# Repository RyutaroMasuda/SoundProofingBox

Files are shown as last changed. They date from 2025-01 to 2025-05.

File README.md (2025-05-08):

# SoundProofingBox_RZ420
RZ420用の防音箱。assy-SoundProofingBox_RZ420.SLDASMが最上位アセンブリです。部品リストもあります。わわわ
## License

MIT License

Copyright (c) 2025 隆太郎 益田

Permission is hereby granted, free of charge, to any person obtaining a copy...

## 設計外観

## 加工時の注意
- MDFとアルミフレームの接合分のねじ穴は、端から10mmでさえあれば、縦の位置はがばがばでもよい。専用の治具を別途プリント部品で製作するのが良い。
   
- 必要な加工はMDFに対するねじ穴開けと配線用の100mmの円形穴のみである。
  - 円形穴はサークルカッタを使用する。
- 鬼目ナットはM5のものはねじ込み型で、M3のものは打ち込み型である。これはM3に打ち込み型しかなかったからである。
  - 打ち込み型の方が取れやすいらしい。
  - 鬼目ナットは貫通穴ではないので注意すること。
## 組み立て時の注意
- 振動用にすべてのねじにロックタイト中強度を塗布する。
  - ねじを締める前にパーツクリーナで洗浄するのがbetter
- 面倒だったので防音マットをCAD上に反映させていない。
  - 防音マットは300-300-0.9で、カッターやハサミで切断可能なので、組み立て時に同時に加工する。
  - 専用の両面テープで接着する。

## 参考文献
https://www.neji-concier.com/column/what-kind-of-onime-nut.html
## 謝辞
RZ420本体の方のCADを作ったのは12期の木野本さんです。大変助かりました。ありがとう。

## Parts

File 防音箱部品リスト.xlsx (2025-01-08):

入力順 | 品名 | 型番 | 必要個数 | 予備 | 購入サイト | 合計金額（税込み） | 発注先 | 備考
1 | 防音箱用M3ねじ |  | 1 | 0 | https://amzn.asia/d/9brNjJE | 1399 | amazon
2 | サークルカッター |  | 1 | 0 | https://amzn.asia/d/35P8lY7 | 1730 | amazon | 100mmMDF穴あけ用
3 | ねじロック |  | 1 | 0 | https://www.amazon.co.jp/%E3%83%98%E3%83%B3%E3%82%B1%E3%83%AB%E3%82%B8%E3%83%A3%E3%83%91%E3%83%B3-Henkel-Japan-LOCTITE-%E9%87%91%E5%B1%9E%E8%A3%BD%E3%81%AD%E3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 | 881 | amazon
4 | 木工用ドリルビット |  | 1 | 0 | https://www.amazon.co.jp/YOKOCUT-%E3%83%89%E3%83%AA%E3%83%AB%E3%83%93%E3%83%83%E3%83%88%E3%82%BB%E3%83%83%E3%83%88-%E6%9C%A8%E5%B7%A5%E7%94%A8%E3%83%89%E3%83%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 | 900 | amazon
5 | MDF 595×640×15 |  | 1 | 0 | https://www.zaiichi.com/mdf/1500.html |  | 木工素材の材木屋ざいいち | カッティングサービスを利用。金額不明。見積もり申請をサイトから提出
6 | MDF 310×595×15 |  | 1 | 0 | https://www.zaiichi.com/mdf/1500.html |  | 木工素材の材木屋ざいいち | カッティングサービスを利用。金額不明。見積もり申請をサイトから提出
7 | MDF 595×615×15 |  | 1 | 0 | https://www.zaiichi.com/mdf/1500.html |  | 木工素材の材木屋ざいいち | カッティングサービスを利用。金額不明。見積もり申請をサイトから提出
8 | MDF 535×595×15 |  | 1 | 0 | https://www.zaiichi.com/mdf/1500.html |  | 木工素材の材木屋ざいいち | カッティングサービスを利用。金額不明。見積もり申請をサイトから提出
9 | MDF 105×595×15 |  | 1 | 0 | https://www.zaiichi.com/mdf/1500.html |  | 木工素材の材木屋ざいいち | カッティングサービスを利用。金額不明。見積もり申請をサイトから提出
10 | MDF 595×925×15 |  | 1 | 0 | https://www.zaiichi.com/mdf/1500.html |  | 木工素材の材木屋ざいいち | カッティングサービスを利用。金額不明。見積もり申請をサイトから提出
11 | MDF 640×955×15 |  | 2 | 0 | https://www.zaiichi.com/mdf/1500.html |  | 木工素材の材木屋ざいいち | カッティングサービスを利用。金額不明。見積もり申請をサイトから提出
12 | アルミフレーム | NFS5-2020-555.0 | 3 | 0 | https://jp.misumi-ec.com/vona2/detail/110311092599/?HissuCode=NFS5-2020-555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 | 858 | ミスミ
13 | アルミフレーム | NFS5-2020-570.0 | 4 | 0 | https://jp.misumi-ec.com/vona2/detail/110311092599/?HissuCode=NFS5-2020-570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 | 1144 | ミスミ
14 | アルミフレーム | NFS5-2020-925.0 | 4 | 0 | https://jp.misumi-ec.com/vona2/detail/110311092599/?HissuCode=NFS5-2020-925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 | 1892 | ミスミ
15 | ブラケット | HBLFSN5 | 20 | 0 | https://jp.misumi-ec.com/vona2/detail/110300437260/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 | 1540 | ミスミ
16 | 座金 | E-GSPWF5 | 40 | 160 | https://jp.misumi-ec.com/vona2/detail/110311012589/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 | 1320 | ミスミ
17 | M5×12ねじ | E-GSCB5-12 | 40 | 160 | https://jp.misumi-ec.com/vona2/detail/110310861029/?searchFlow=results2products | 1320 | ミスミ
18 | 後入れバネナット(1パック) | PACK-HNTP5-5 | 1 | 0 | https://jp.misumi-ec.com/vona2/detail/110302608410/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 | 4676 | ミスミ | 100個入り(96個使用)
19 | 超極低頭ボルトM5×20 | E-GCBSTSR5-20 | 60 | 10 | https://jp.misumi-ec.com/vona2/detail/110311091879/?HissuCode=E-GCBSTSR5-20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 | 5929 | ミスミ
20 | 蝶番 | C-HHFL5-2 | 4 | 0 | https://jp.misumi-ec.com/vona2/detail/110310364679/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 | 1452 | ミスミ
21 | 取っ手 | C-NUWANS10-80-27 | 2 | 0 | https://jp.misumi-ec.com/vona2/detail/110310457469/?HissuCode=C-NUWANS10-80-27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 | 594 | ミスミ
22 | マグネットキャッチ | MGCST30 | 2 | 0 | https://jp.misumi-ec.com/vona2/detail/110302027570/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 | 1067 | ミスミ
23 | 鬼目ナットM3×8.5(1パック) | 41754833 | 1 | 0 | https://www.monotaro.com/p/4175/4833/?t.q=m3%20%8BS%96%DA%83i%83b%83g | 549 | モノタロウ
24 | 鬼目ナットM5×13(1パック) | 41755174 | 2 | 0 | https://www.monotaro.com/p/4175/5174/?t.q=%8BS%96%DA%83i%83b%83g%20m5 | 489 | モノタロウ | １パック10個入り（16個使用）
25 | 六角穴付き皿ボルトM5×12(1パック) | 5525931 | 1 | 0 | https://www.monotaro.com/p/0552/5931/ | 647 | モノタロウ
26 | 六角穴付き皿ボルトM3×10(1パック) | 5527471 | 1 | 0 | https://www.monotaro.com/p/0552/7471/?t.q=%98Z%8Ap%8C%8A%95t%82%AB%20%8EM%83%7B%83%8B%83g%20M3 | 956 | モノタロウ
27 | 六角穴付き皿ボルトM3×16(1パック) | 5527514 | 1 | 0 | https://www.monotaro.com/p/0552/7514/ | 956 | モノタロウ
28 | パーツクリーナー | 5827954 | 1 | 0 | https://www.monotaro.com/p/0582/7954/?t.q=%83p%81%5B%83c%20%83N%83%8A%81%5B%83i%81%5B | 670 | モノタロウ
29 | キムタオル | 32575794 | 1 | 0 | https://www.monotaro.com/p/3257/5794/?t.q=%83L%83%80%83%8F%83C%83v | 659 | モノタロウ
30 | 吸音パネル |  | 3 | 0 | https://item.rakuten.co.jp/whiteleaf-mart/square-sound_absorbing_panel/?variantId=314 | 11940 | 楽天 | １パック12枚入り(28枚使用)
31 | 両面テープ |  | 3 | 0 | https://item.rakuten.co.jp/whiteleaf-mart/strong_double-sided_tape/ | 2490 | 楽天
 |  |  |  |  | 合計金額 | 31628

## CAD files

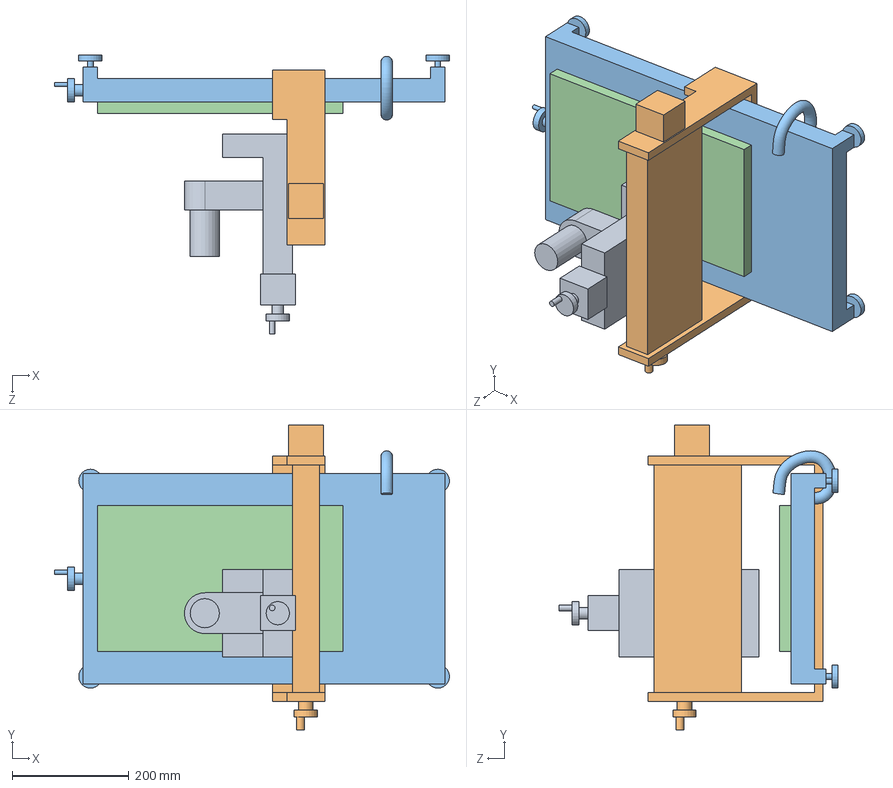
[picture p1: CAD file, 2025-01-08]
RZ420_kh/RZ420.SLDASM
676.5 x 522.0 x 477.0 mm
base_RZ420
Part2_RZ420
Part4_RZ420
part3_RZ420

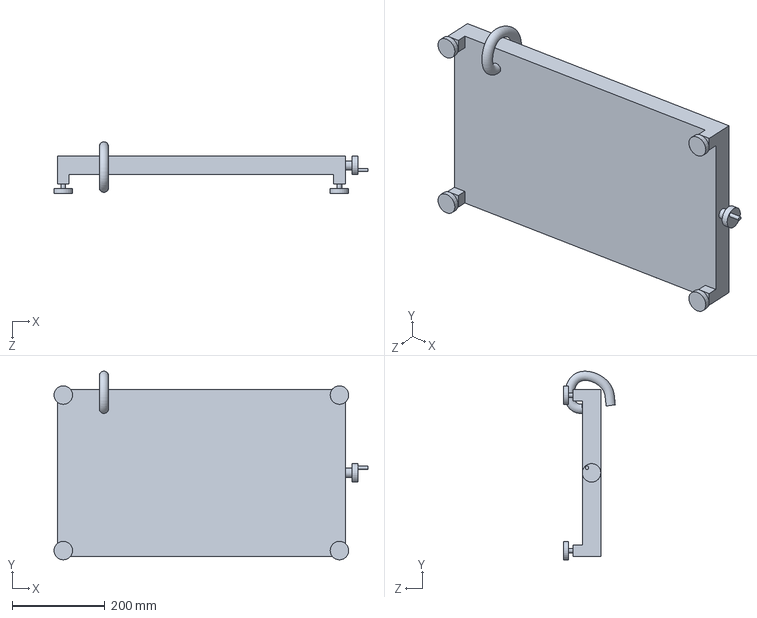
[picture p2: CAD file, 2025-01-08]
RZ420_kh/Part2_RZ420.SLDPRT
676.5 x 406.6 x 111.1 mm

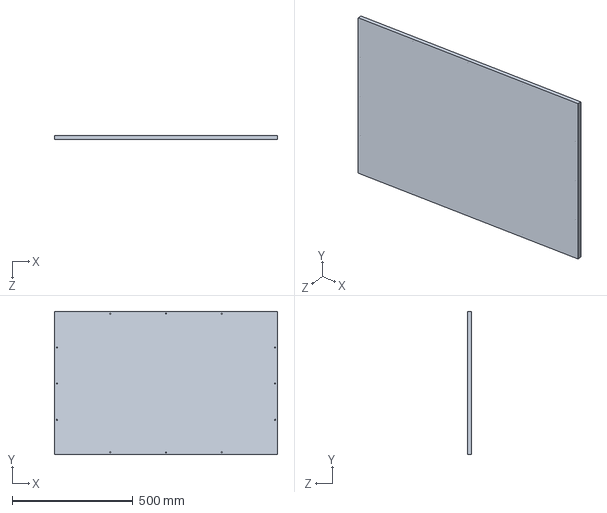
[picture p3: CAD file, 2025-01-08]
plate_back.SLDPRT
925.0 x 595.0 x 15.0 mm

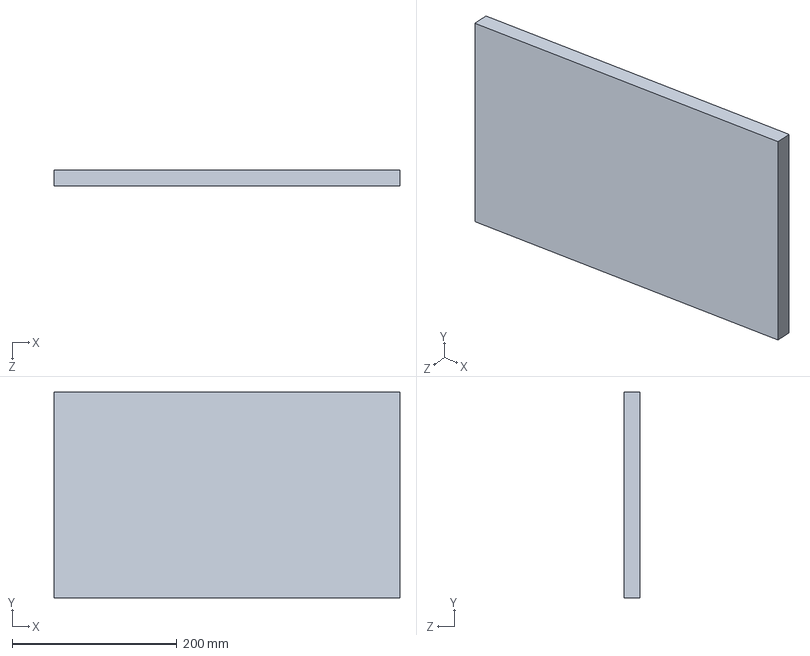
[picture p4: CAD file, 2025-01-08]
RZ420_kh/base_RZ420.SLDPRT
420.0 x 250.0 x 20.0 mm

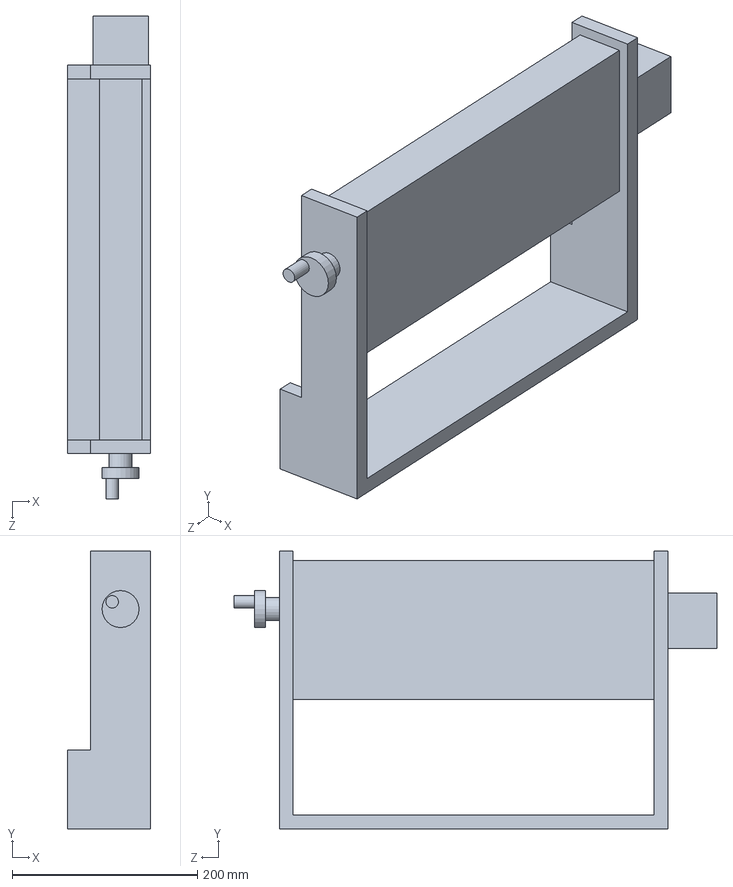
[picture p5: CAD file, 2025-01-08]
RZ420_kh/Part4_RZ420.SLDPRT
90.0 x 300.0 x 522.0 mm

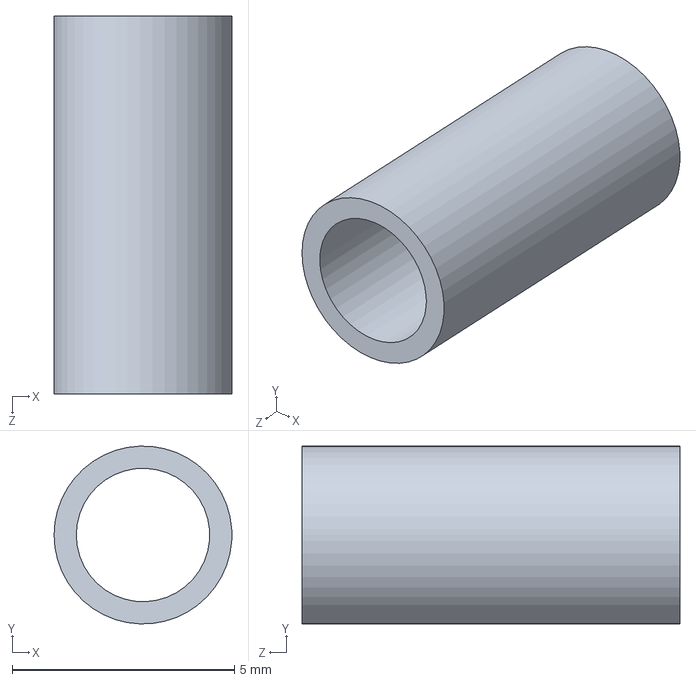
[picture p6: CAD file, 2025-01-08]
Onimenut_m3.SLDPRT
4.00 x 4.00 x 8.50 mm

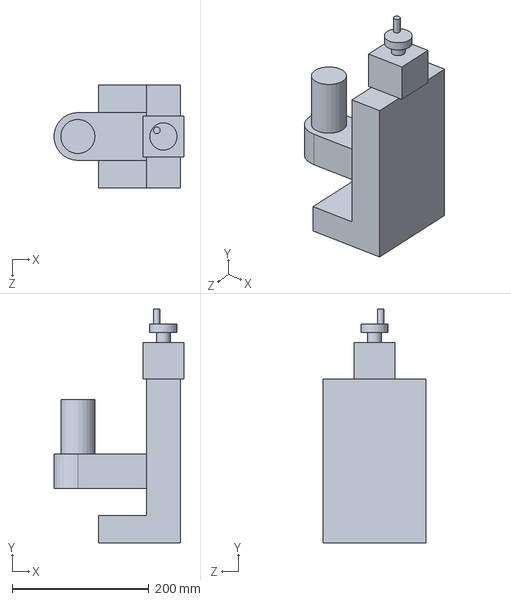
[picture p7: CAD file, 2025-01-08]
RZ420_kh/part3_RZ420.SLDPRT
189.8 x 342.0 x 150.0 mm

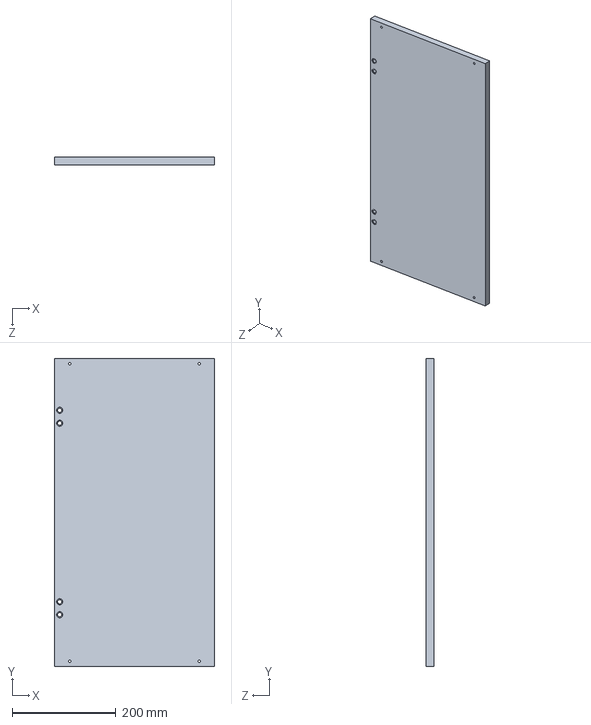
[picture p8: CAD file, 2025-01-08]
plate_front_small.SLDPRT
310.0 x 595.0 x 15.0 mm

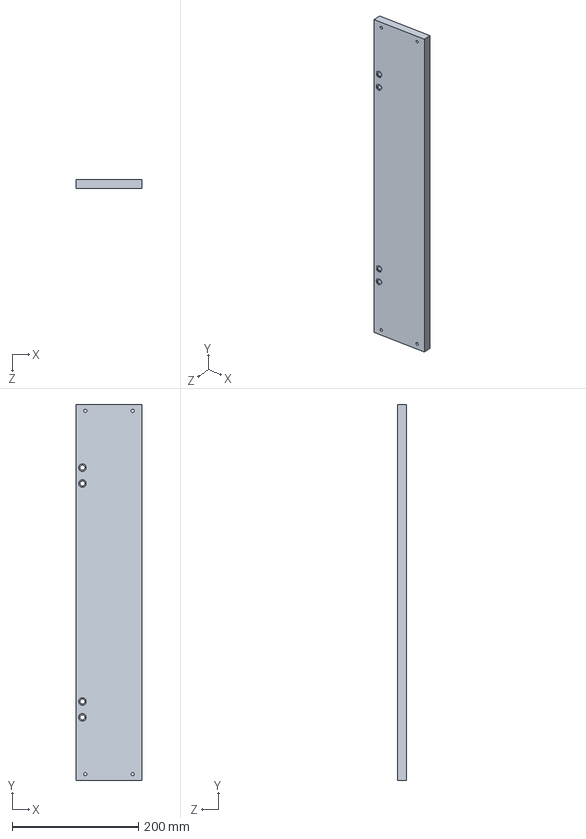
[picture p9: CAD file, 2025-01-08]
plate_left_small.SLDPRT
105.0 x 595.0 x 15.0 mm

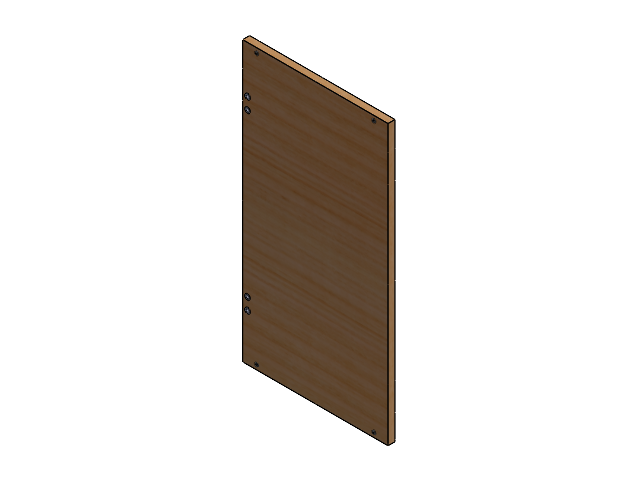
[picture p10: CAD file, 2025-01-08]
s-assy-frontsmall.SLDASM
plate_front_small
Onimenut_m5 x 4
MISUMI_E-GCBSTSR5-20 x 4
MISUMI_HNTP5-5 x 4

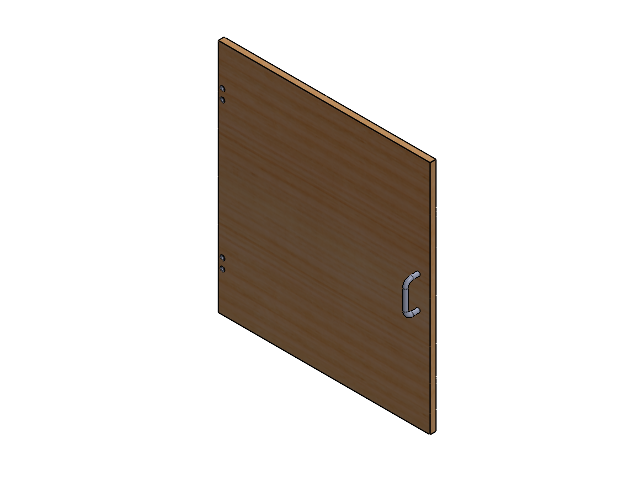
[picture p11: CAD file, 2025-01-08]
s-assy-leftlarge.SLDASM
plate_left_large
Onimenut_m5 x 4
MISUMI_C-NUWANS10-80-27
Onimenut_m3 x 4
MISUMI_E-GCBSTSR5-20 x 2

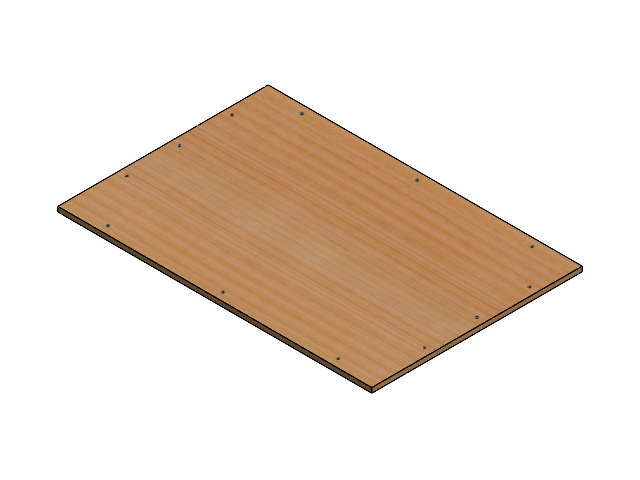
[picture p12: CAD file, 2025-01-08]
s-assy-above.SLDASM
plate_above
MISUMI_E-GCBSTSR5-20 x 12
MISUMI_HNTP5-5 x 12

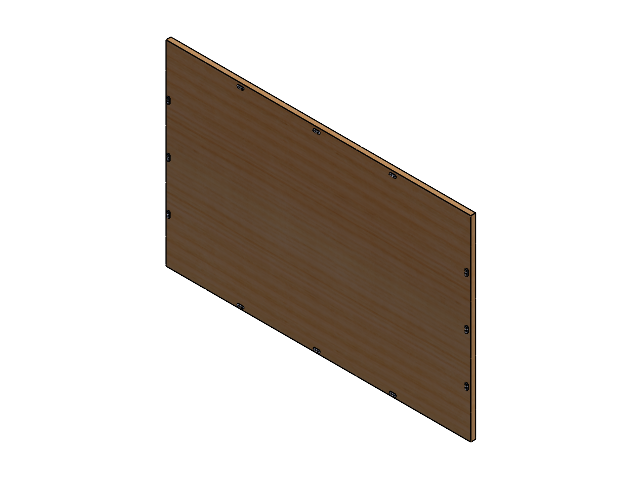
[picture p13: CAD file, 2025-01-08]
s-assy-back.SLDASM
plate_back
MISUMI_E-GCBSTSR5-20 x 12
MISUMI_HNTP5-5 x 12

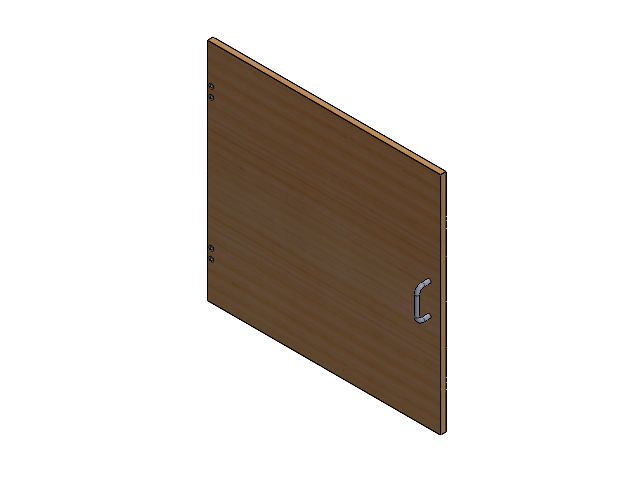
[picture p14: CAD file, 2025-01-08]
s-assy-frontlarge.SLDASM
plate_front_large
Onimenut_m5 x 4
MISUMI_C-NUWANS10-80-27
Onimenut_m3 x 4
MISUMI_E-GCBSTSR5-20 x 2

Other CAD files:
s-assy-leftsmall.SLDASM
s-assy-rightside.SLDASM
s-s-assy-bracket.SLDASM
C-HHFL5-2/BASE-L_MISUMI_C-HHFL5-2.SLDPRT
C-HHFL5-2/BASE-R_MISUMI_C-HHFL5-2.SLDPRT
C-HHFL5-2/ERING_MISUMI_C-HHFL5-2.SLDPRT
C-HHFL5-2/MISUMI_C-HHFL5-2.SLDASM
C-HHFL5-2/SHAFT_MISUMI_C-HHFL5-2.SLDPRT
C-HHFL5-2/SPACER_MISUMI_C-HHFL5-2.SLDPRT
HBLFSN5/BRACKET_MISUMI_HBLFSN5.SLDPRT
HBLFSN5/MISUMI_HBLFSN5.SLDASM
HBLFSN5/NAT-M5-1_MISUMI_HBLFSN5.SLDPRT
HBLFSN5/NAT-M5-2_MISUMI_HBLFSN5.SLDPRT
HBLFSN5/NAT-M5-3_MISUMI_HBLFSN5.SLDPRT
HBLFSN5/NAT-M5-4_MISUMI_HBLFSN5.SLDPRT
HBLFSN5/NEZI-M5x10L_MISUMI_HBLFSN5.SLDPRT
HBLFSN5/NEZI-M5x12L_MISUMI_HBLFSN5.SLDPRT
MGCST30/MAGNET_MISUMI_MGCST30.SLDPRT
MGCST30/MISUMI_MGCST30.SLDASM
MGCST30/PLATE_MISUMI_MGCST30.SLDPRT
MISUMI_C-NUWANS10-80-27.SLDPRT
MISUMI_E-GCBSTSR5-20.SLDPRT
MISUMI_E-GSFB5-12.SLDPRT
MISUMI_HFBCM3-12.SLDPRT
MISUMI_HNTP5-5.SLDPRT
MISUMI_NFS5-2020-555.0.SLDPRT
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

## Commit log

2025-01-08 pack assy
    add assy
    [BASE-L_MISUMI_C-HHFL5-2.SLDPRT, BASE-R_MISUMI_C-HHFL5-2.SLDPRT, BRACKET_MISUMI_HBLFSN5.SLDPRT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]
2025-01-09 add step file
    [assy-SoundProofingBox_RZ420.STEP]
